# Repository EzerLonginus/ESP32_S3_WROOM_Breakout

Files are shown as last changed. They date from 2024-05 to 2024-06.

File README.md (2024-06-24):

# ESP32_S3_WROOM_Breakout
Breakout Board for ESP32 S3 WROOM

This board is a simple breakout for the ESP32 S3 WROOM.  The interface includes the standard reset and boot button, with a USB to UART CH340G converter, and a 3V3 regulator.  All GPIO pins are broken out to standard 2.54mm headers.  USB-C reseptacle connector is used, but at the USB 2.0 standard. 

## Purpose
This is mostly an excersize in designing an ESP32 module for inclusion in other projects.  Once this design is functional, I'll start using it as a template for more custom oriented projects involving the chip (or some variant).  I decided on the ESP S3 WROOM, because the S2 Solo seems to be slowly phasing out, and also doesn't have bluetooth functionality.  Depending on how this excersize goes, I may start designing boards with just the bare chip (no built in WiFi antenna, SPI Flash, etc).    

## Scematic
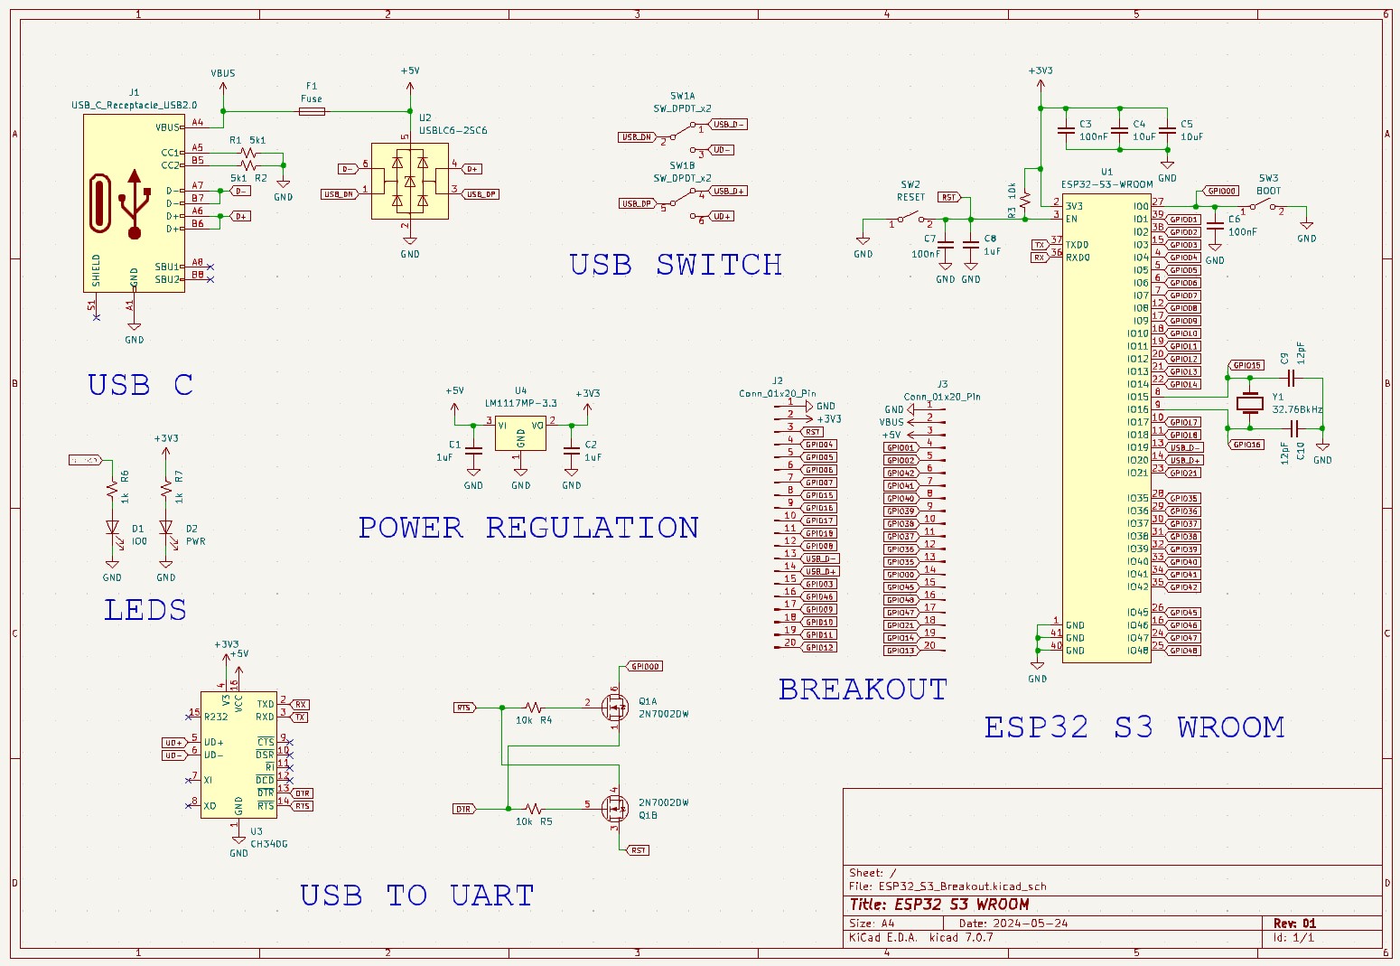
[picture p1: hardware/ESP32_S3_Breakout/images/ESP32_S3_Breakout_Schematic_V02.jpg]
ESP32 S3 WROOM Schematic


## Layout
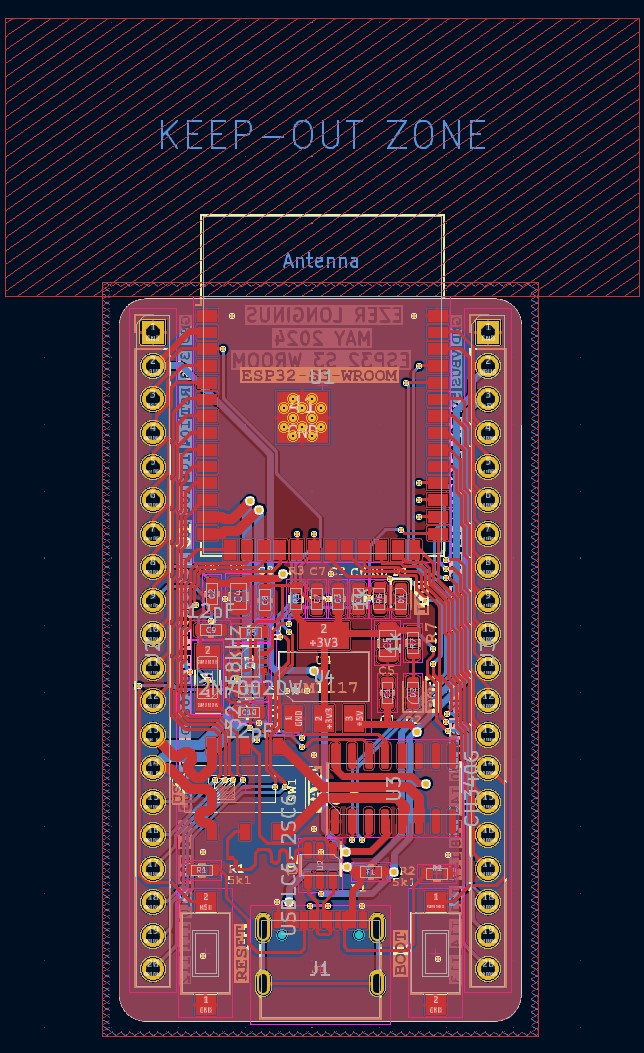
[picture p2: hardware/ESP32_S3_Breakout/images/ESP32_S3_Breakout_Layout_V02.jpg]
ESP32 S3 WROOM Layout


## Current State of Affairs
### Version 1
* Populate and test board
* Upload some blink/hello world sketch
* Fix the inevitable issue that I missed during production



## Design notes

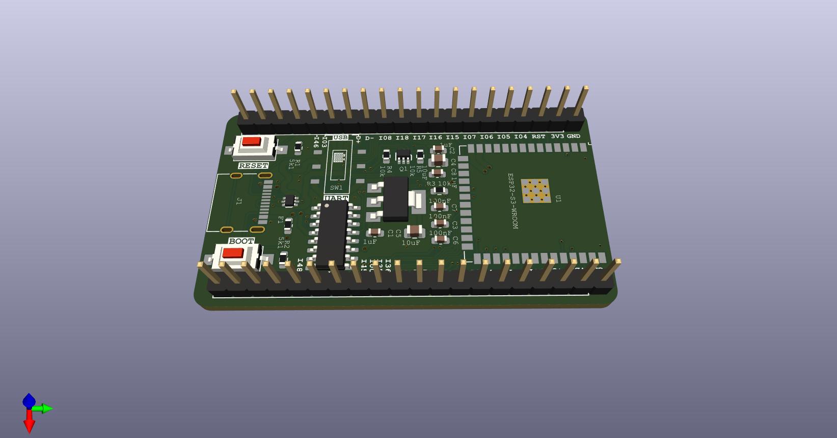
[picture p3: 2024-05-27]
hardware/ESP32_S3_Breakout/images/ESP32_S3_Breakout_3D_View.jpg

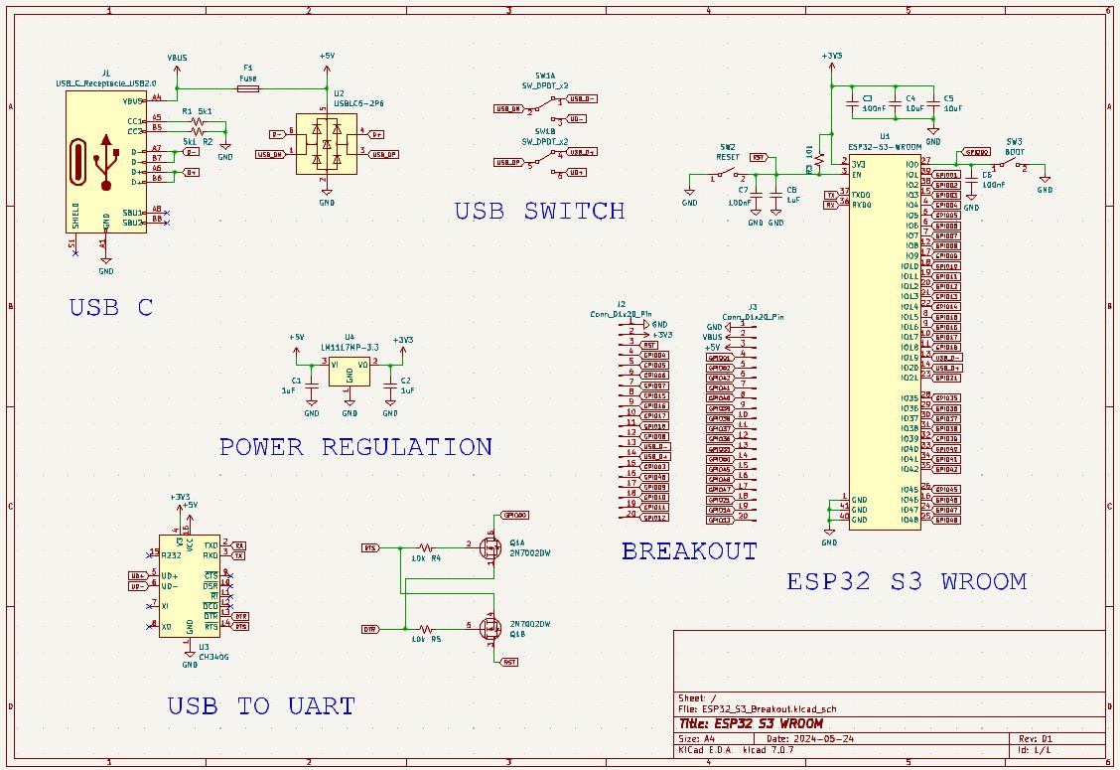
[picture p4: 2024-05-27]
hardware/ESP32_S3_Breakout/images/ESP32_S3_Breakout_Schematic_V01.jpg

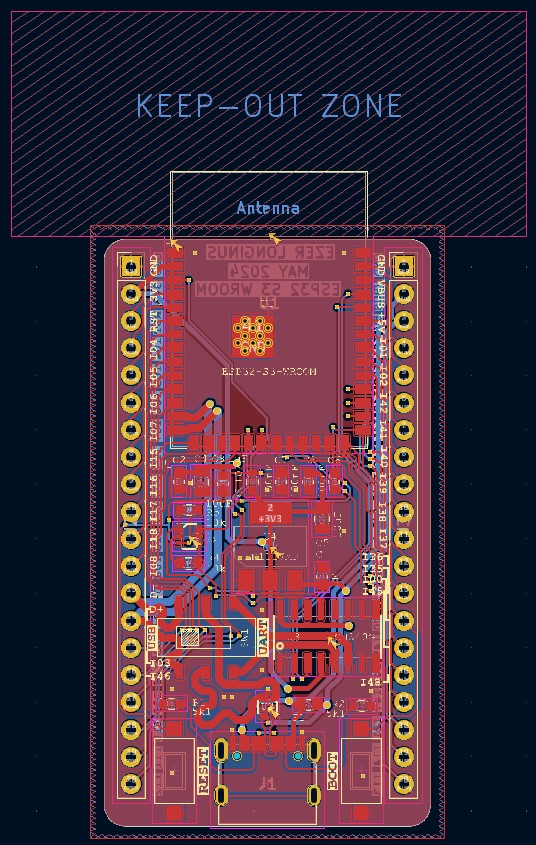
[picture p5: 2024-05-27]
hardware/ESP32_S3_Breakout/images/ESP32_S3_Breakout_Layout_V01.jpg

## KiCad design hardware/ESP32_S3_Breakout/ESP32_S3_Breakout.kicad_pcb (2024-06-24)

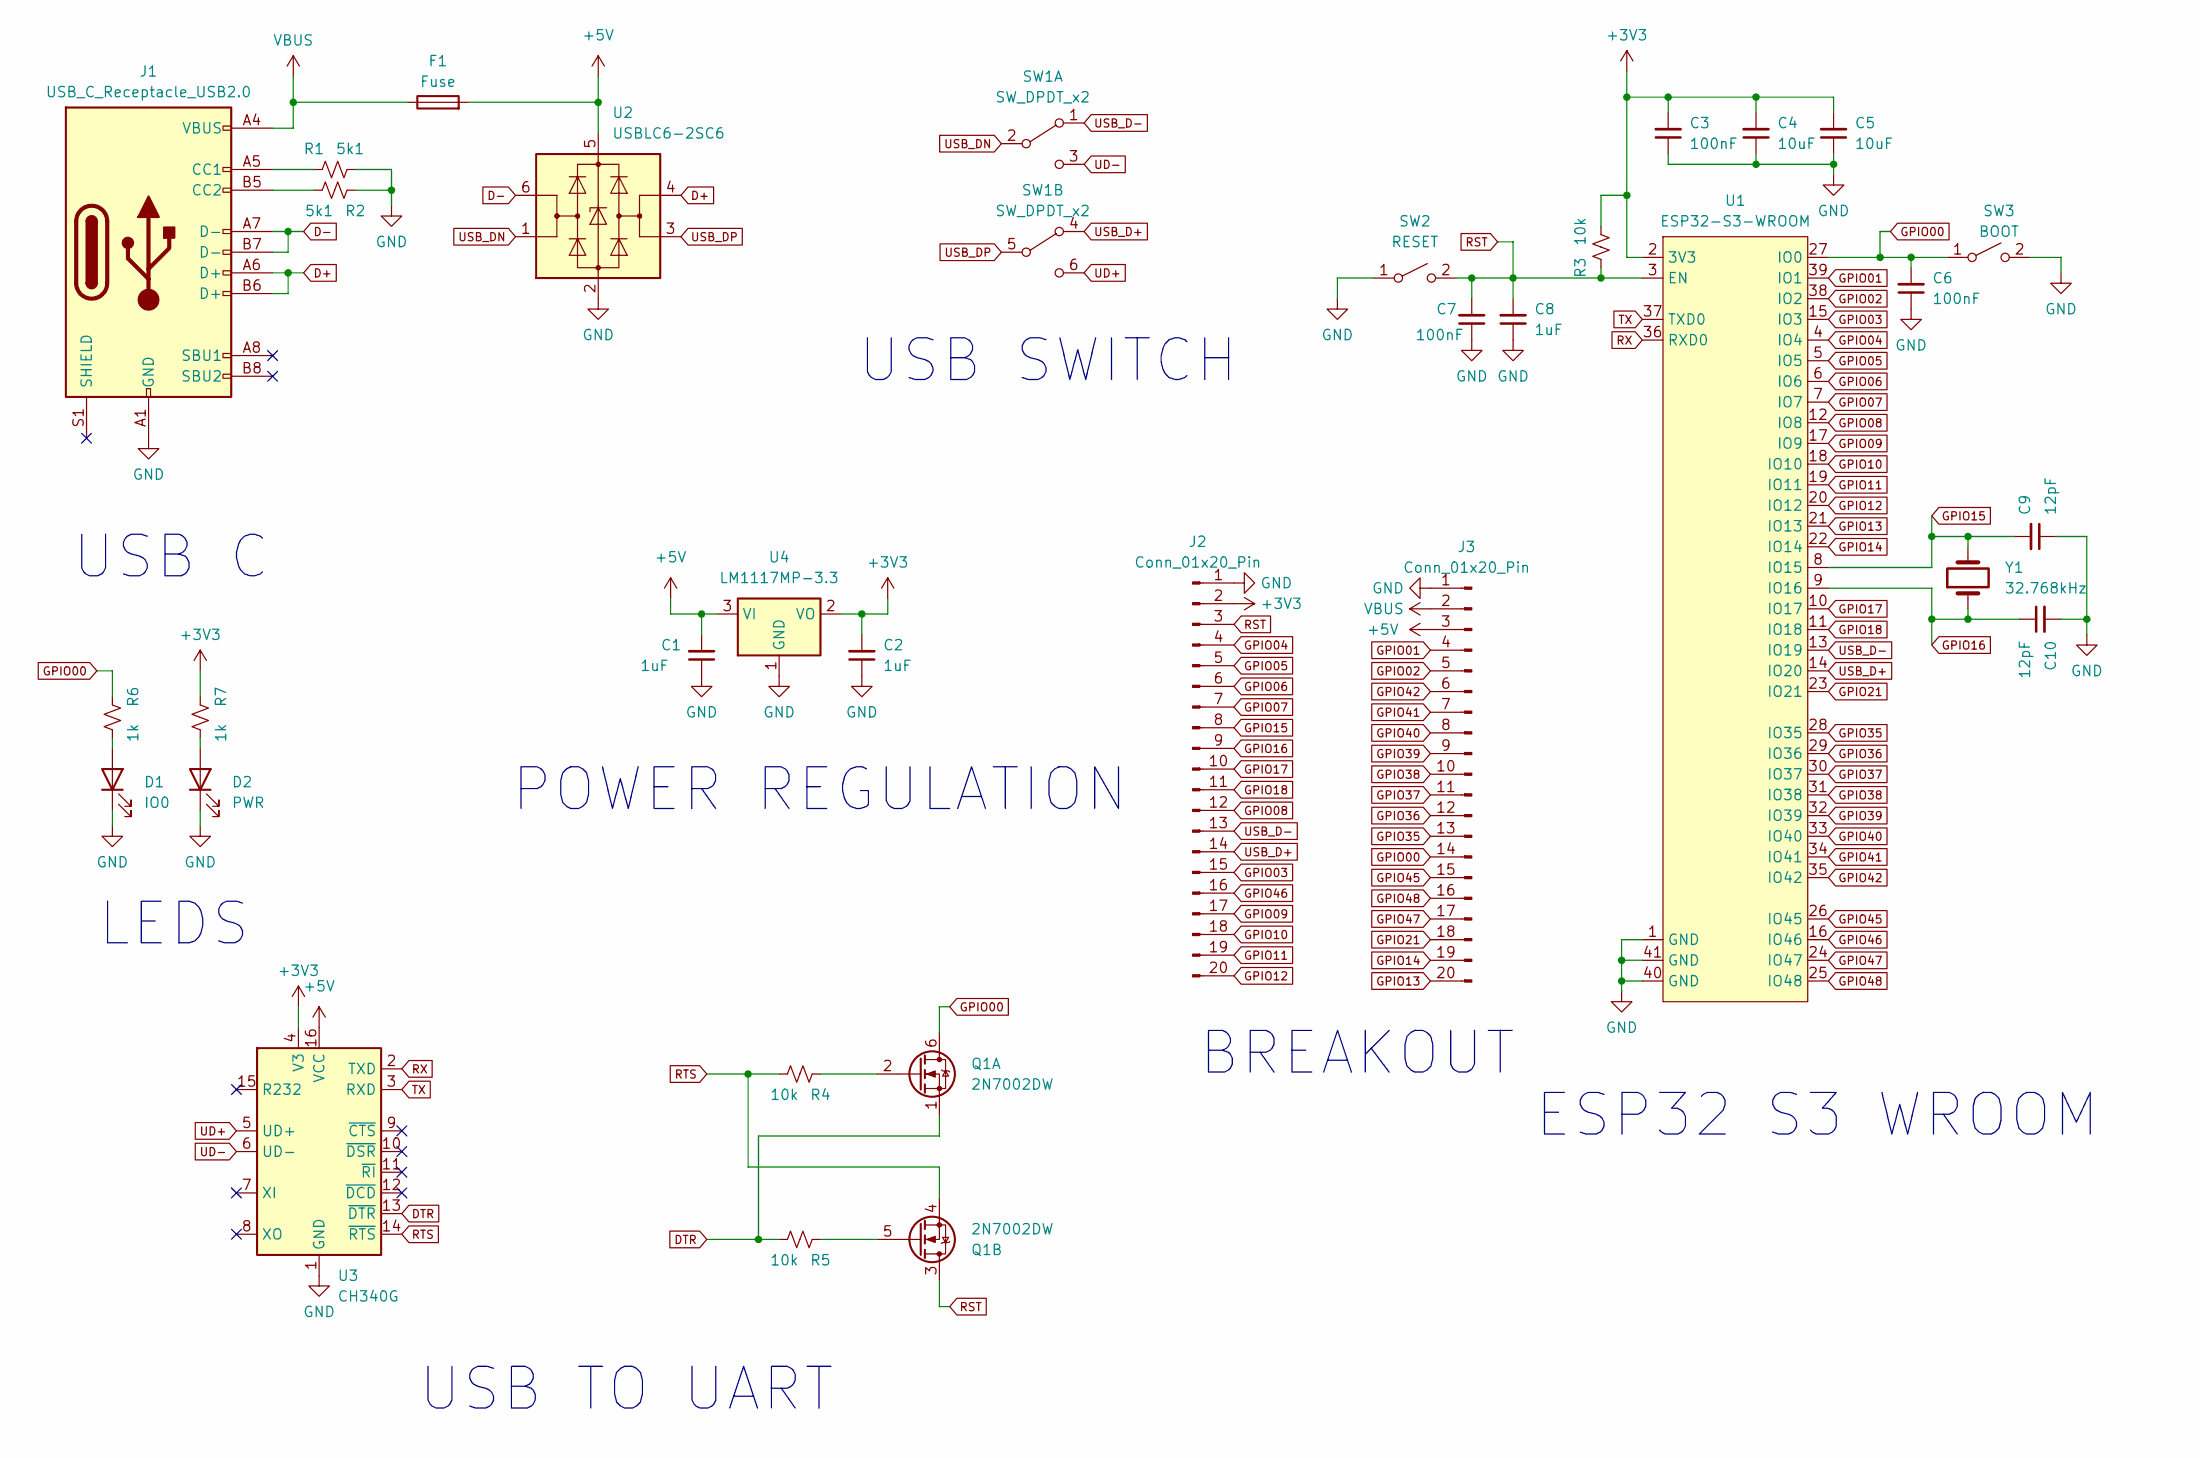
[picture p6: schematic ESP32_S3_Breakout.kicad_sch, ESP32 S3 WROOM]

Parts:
C1, C2, C8: 1uF; C_0603_1608Metric
C3, C6, C7: 100nF; C_0603_1608Metric
C4, C5: 10uF; C_0805_2012Metric
C9, C10: 12pF; C_0603_1608Metric
D1: IO0; LED_0603_1608Metric
D2: PWR; LED_0603_1608Metric
F1: Fuse; Fuse_0603_1608Metric
J1: USB_C_Receptacle_USB2.0; USB_C_Receptacle_G-Switch_GT-USB-7010ASV
J2, J3: Conn_01x20_Pin; PinHeader_1x20_P2.54mm_Vertical
Q1: 2N7002DW; SOT-363_SC-70-6
R1, R2: 5k1; R_0603_1608Metric
R3, R4, R5: 10k; R_0603_1608Metric
R6, R7: 1k; R_0603_1608Metric
SW1: SW_DPDT_x2; SMD DPDT Toggle SS-3235S-L1
SW2: RESET; SW_SPST_CK_RS282G05A3
SW3: BOOT; SW_SPST_CK_RS282G05A3
U1: ESP32-S3-WROOM; ESP32-S3-WROOM-1
U2: USBLC6-2SC6; SOT-23-6
U3: CH340G; SOIC-16_3.9x9.9mm_P1.27mm
U4: LM1117MP-3.3; SOT-223-3_TabPin2
Y1: 32.768kHz; Crystal_SMD_EuroQuartz_EQ161-2Pin_3.2x1.5mm_HandSoldering

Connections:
+3V3: C2.2, C3.2, C4.2, C5.2, J2.2, R3.2, R7.1, U1.2 (3V3), U3.4 (V3), U4.2 (VO)
+5V: C1.2, F1.2, J3.3, U2.5 (VBUS), U3.16 (VCC), U4.3 (VI)
D+: J1.A6 (D+), J1.B6 (D+), U2.4 (I/O2)
D-: J1.A7 (D-), J1.B7 (D-), U2.6 (I/O1)
DTR: Q1.1 (S), R5.2, U3.13 (~DTR)
GND: C1.1, C2.1, C3.1, C4.1, C5.1, C6.1, C7.1, C8.1, C9.1, C10.2, D1.1 (K), D2.1 (K), J1.A1 (GND), J1.A12 (GND), J1.B1 (GND), J1.B12 (GND), J2.1, J3.1, R1.2, R2.1, SW2.1 (A), SW3.2 (B), U1.1 (GND), U1.40 (GND), U1.41 (GND), U2.2 (GND), U3.1 (GND), U4.1 (GND)
GPIO00: C6.2, J3.14, Q1.6 (D), R6.1, SW3.1 (A), U1.27 (IO0)
GPIO01: J3.4, U1.39 (IO1)
GPIO02: J3.5, U1.38 (IO2)
GPIO03: J2.15, U1.15 (IO3)
GPIO04: J2.4, U1.4 (IO4)
GPIO05: J2.5, U1.5 (IO5)
GPIO06: J2.6, U1.6 (IO6)
GPIO07: J2.7, U1.7 (IO7)
GPIO08: J2.12, U1.12 (IO8)
GPIO09: J2.17, U1.17 (IO9)
GPIO10: J2.18, U1.18 (IO10)
GPIO11: J2.19, U1.19 (IO11)
GPIO12: J2.20, U1.20 (IO12)
GPIO13: J3.20, U1.21 (IO13)
GPIO14: J3.19, U1.22 (IO14)
GPIO15: C9.2, J2.8, U1.8 (IO15), Y1.2
GPIO16: C10.1, J2.9, U1.9 (IO16), Y1.1
GPIO17: J2.10, U1.10 (IO17)
GPIO18: J2.11, U1.11 (IO18)
GPIO21: J3.18, U1.23 (IO21)
GPIO35: J3.13, U1.28 (IO35)
GPIO36: J3.12, U1.29 (IO36)
GPIO37: J3.11, U1.30 (IO37)
GPIO38: J3.10, U1.31 (IO38)
GPIO39: J3.9, U1.32 (IO39)
GPIO40: J3.8, U1.33 (IO40)
GPIO41: J3.7, U1.34 (IO41)
GPIO42: J3.6, U1.35 (IO42)
GPIO45: J3.15, U1.26 (IO45)
GPIO46: J2.16, U1.16 (IO46)
GPIO47: J3.17, U1.24 (IO47)
GPIO48: J3.16, U1.25 (IO48)
unnamed: D1.2 (A), R6.2
unnamed: D2.2 (A), R7.2
unnamed: J1.A5 (CC1), R1.1
unnamed: J1.B5 (CC2), R2.2
unnamed: Q1.2 (G), R4.1
unnamed: Q1.5 (G), R5.1
RST: C7.2, C8.2, J2.3, Q1.3 (D), R3.1, SW2.2 (B), U1.3 (EN)
RTS: Q1.4 (S), R4.2, U3.14 (~RTS)
RX: U1.36 (RXD0), U3.2 (TXD)
TX: U1.37 (TXD0), U3.3 (RXD)
UD+: SW1.6 (C), U3.5 (UD+)
UD-: SW1.3 (C), U3.6 (UD-)
USB_D+: J2.14, SW1.4 (A), U1.14 (IO20)
USB_D-: J2.13, SW1.1 (A), U1.13 (IO19)
USB_DN: SW1.2 (B), U2.1 (I/O1)
USB_DP: SW1.5 (B), U2.3 (I/O2)
VBUS: F1.1, J1.A4 (VBUS), J1.A9 (VBUS), J1.B4 (VBUS), J1.B9 (VBUS), J3.2

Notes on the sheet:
USB C
BREAKOUT
LEDS
ESP32 S3 WROOM
USB TO UART
USB SWITCH
POWER REGULATION

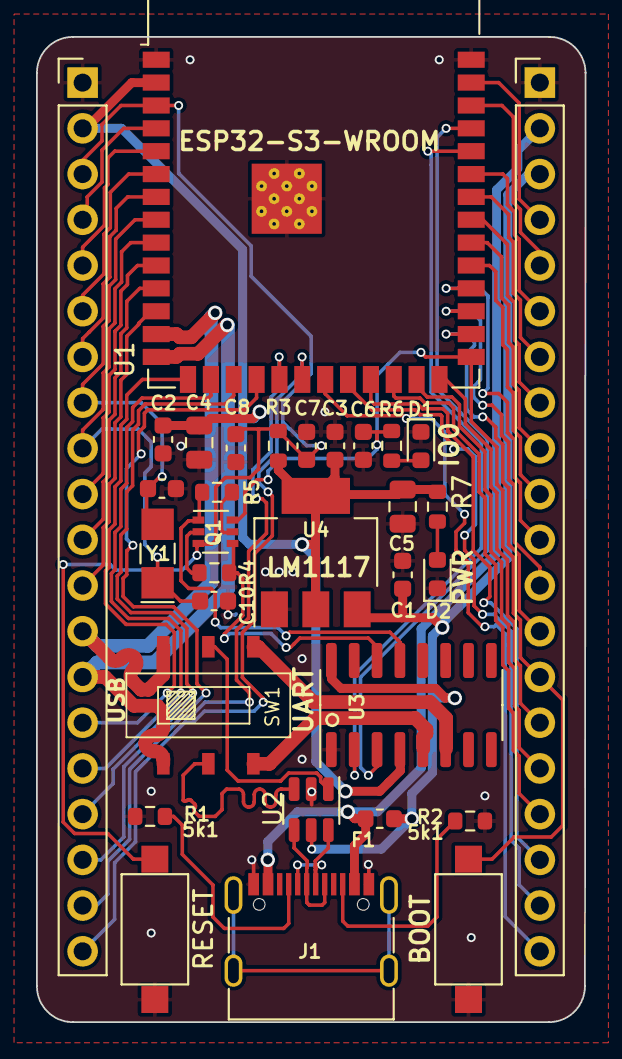
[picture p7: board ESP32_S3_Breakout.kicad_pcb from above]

Board: 2 copper layers, 30.5 x 54.7 mm, 32 parts (0 on the bottom side), 55 nets.

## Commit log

2024-05-27 Initial Commit for ESP32 S3 design
    [ESP32_S3_Breakout-B_Cu.gbr, ESP32_S3_Breakout-B_Mask.gbr, ESP32_S3_Breakout-B_Paste.gbr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]
2024-06-24 Version 02 - Added LEDs
    [ESP32_S3_Breakout-B_Cu.gbr, ESP32_S3_Breakout-B_Mask.gbr, ESP32_S3_Breakout-B_Paste.gbr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]
